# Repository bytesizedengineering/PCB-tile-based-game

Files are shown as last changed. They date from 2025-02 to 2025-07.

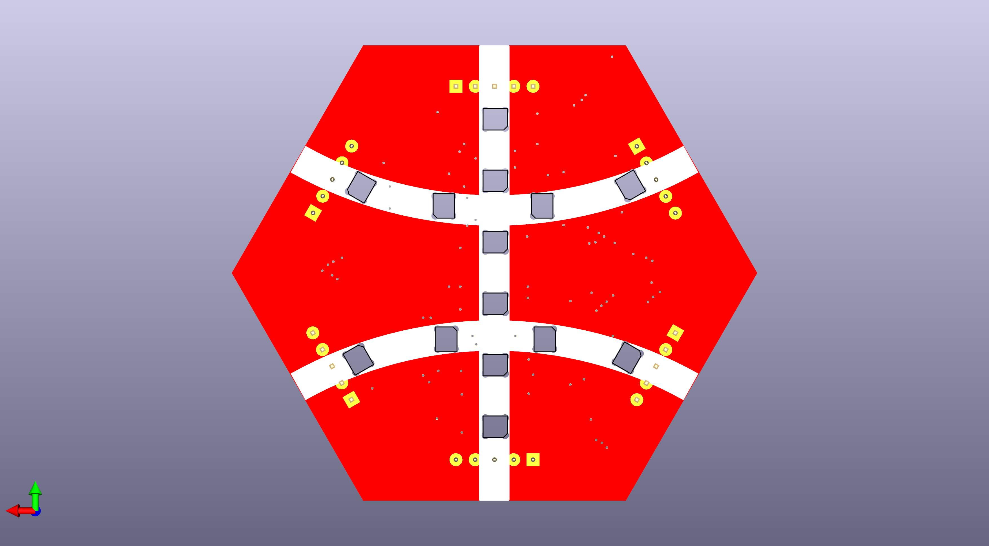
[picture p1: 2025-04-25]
Electrical Design/pcb_tile_game_tile_sos/pcb_tile_game_tile_sos.png

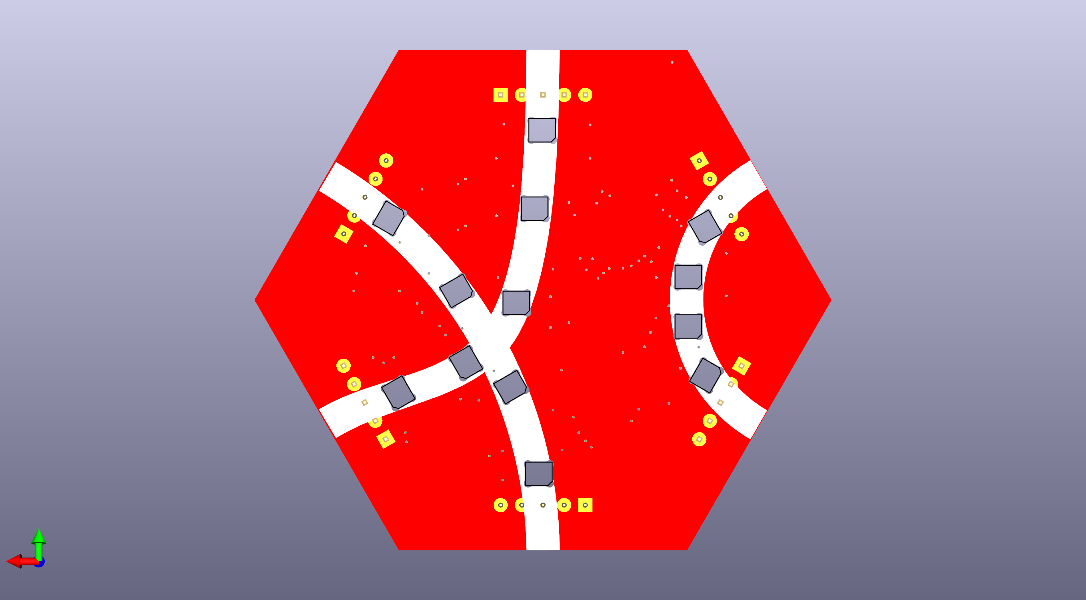
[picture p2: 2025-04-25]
Electrical Design/pcb_tile_game_tile_ssa/pcb_tile_game_tile_ssa.png

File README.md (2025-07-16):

# PCB Tile Based Board Game 

Project Image  
*Whoever completes the longest path wins! But beware of collisions!*  

## 🚀 Overview  
When Zach is not knee-deep in circuits and code, you can probably find him around a table covered in board games. For a long time now, a little project has been brewing in the back of his mind, designing a board game from the ground up, but not just any board game. Zach wants to create a tile-based game where the tiles electronically interact with each other the moment they snap together. It was featured on the Digkey [YouTube channel](https://www.youtube.com/@digikey) in [this video](https://youtu.be/TUmDfVxSnFg?si=vBeNglg9jUsEn66M).  

## 📂 Repository Structure  
```
📁 mechanical_design/   # 3D models (Fusion 360, STLs, STEP files)
📁 electrical_design/   # KiCad PCB and schematic files
📁 firmware/            # Arduino, ESP, or other firmware code
📁 docs/                # PDFs, images, and additional documentation
```

## 🔩 Mechanical Design  
You can access the latest Fusion 360 model here:  
[🔗 View 3D Model in Fusion 360](https://a360.co/4kI0F6f)

## 🏗️ Build Instructions  

### 🖨️ 3D Printing  
- **Recommended Material**: PLA/PETG  
- **Layer Height**: 0.2mm  
- **Supports**: No  

### 🔌 Electronics  
- **Microcontroller**: ATTiny3217  
- **Power Supply**: 5V  
- **PCB Fabrication**: Gerber files included in `electrical_design/` 

### 💾 Firmware Upload  
You can upload code to the ATtiny3217 using the [Adafruit UPDI Friend](https://learn.adafruit.com/adafruit-updi-friend). Here's a quick setup guide for the Arduino IDE:

🧰 What You Need
- Adafruit UPDI Friend
- Arduino IDE
- ATtiny3217 board
- USB-C cable
1. Install MegaTinyCore
2. Select the Board
3. Connect the UPDI Friend
4. Select the Serial Port
5. Upload Code

## 🛒 Bill of Materials (BOM)  
| Part | Description | Purchase Link |
| --- | --- | --- |
| Microcontroller | ATtiny3217 | [DigiKey](https://www.digikey.com/short/wtvwb0pv) |
| Connector | Magnetic Connector Pair | [DigiKey](https://www.digikey.com/short/tv5t94mz) |
| Capacitor | 0.1 µF Ceramic Capacitor | |
| LED | Addressable Reverse-Mount RGB LED | [DigiKey](https://www.digikey.com/short/zhvb3bff) |
| PCB | Custom-designed | |

## 🎥 Video & More Info  
📺 Watch the full build video: [YouTube Video](https://youtu.be/TUmDfVxSnFg?si=vBeNglg9jUsEn66M)  

## 📝 License  
This project is licensed under the **GNU General Public License v3.0**.  
You can read the full text in the [`LICENSE`](LICENSE) file or at [gnu.org](https://www.gnu.org/licenses/gpl-3.0.html).  

## ❤️ Support  
- Found this helpful? Consider supporting me on [Patreon](https://www.patreon.com/ByteSizedEngineering) or [YouTube Memberships](https://www.youtube.com/@ByteSizedEngineering/join).  
- Follow me on [YouTube](https://www.youtube.com/@ByteSizedEngineering), [Instagram](https://www.instagram.com/bytesizedengineering/), and [GitHub](https://github.com/bytesizedengineering).

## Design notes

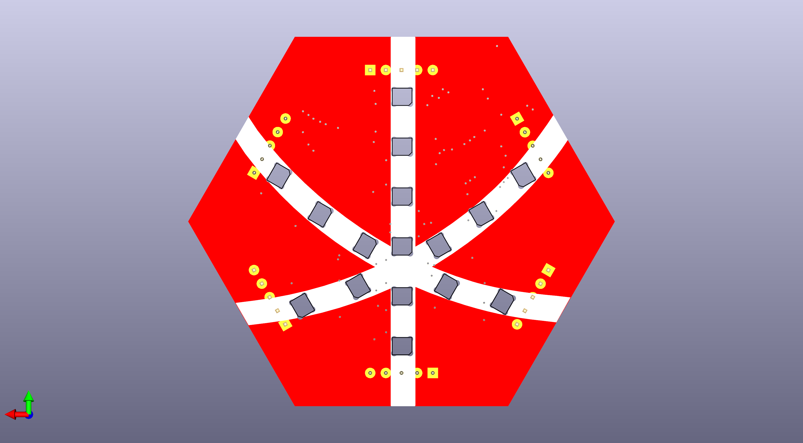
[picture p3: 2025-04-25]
Electrical Design/pcb_tile_game_tile_ooo/pcb_tile_game_tile_ooo.png

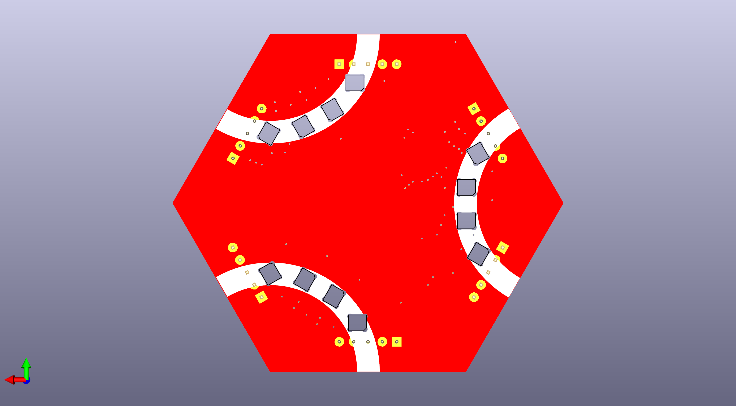
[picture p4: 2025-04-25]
Electrical Design/pcb_tile_game_tile_aaa/pcb_tile_game_tile_aaa.png

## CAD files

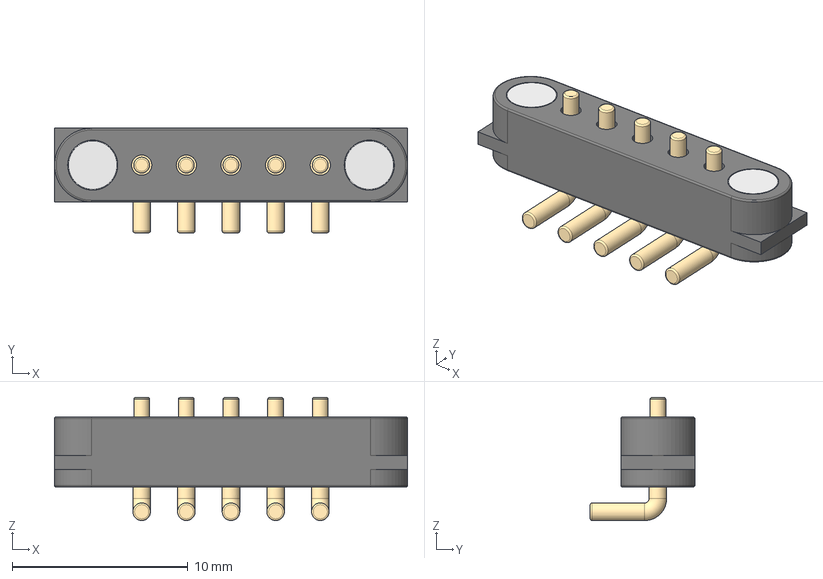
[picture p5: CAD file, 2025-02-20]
Electrical Design/pcb_tile_game_tile_aaa/5359 Mag Connector (5-pin, Right Angle, Pins).step
20.1 x 5.95 x 7.00 mm
Housing
Magnet
Pins
Pin Contacts

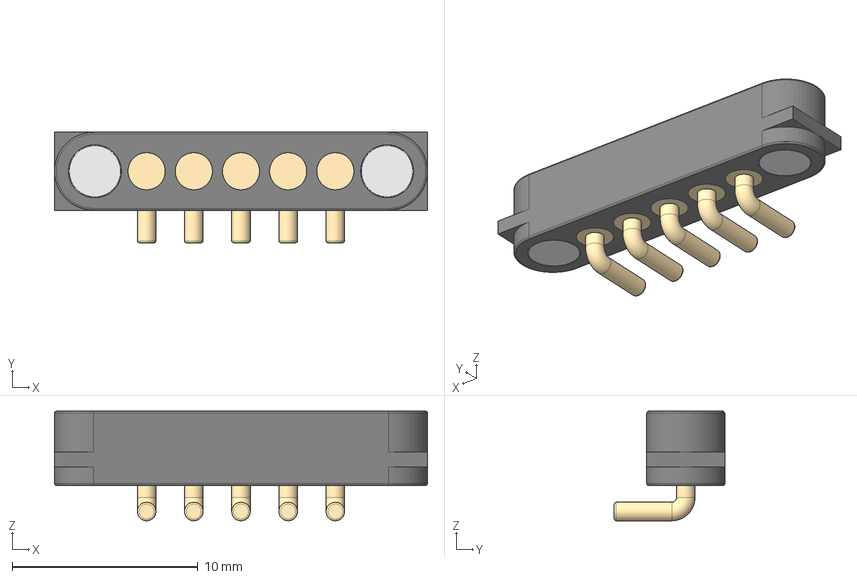
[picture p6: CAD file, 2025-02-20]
Electrical Design/pcb_tile_game_tile_aoa/5359 Mag Connector (5-pin, Right Angle, Pads).step
20.1 x 5.95 x 5.90 mm
Housing
Magnet
Pins

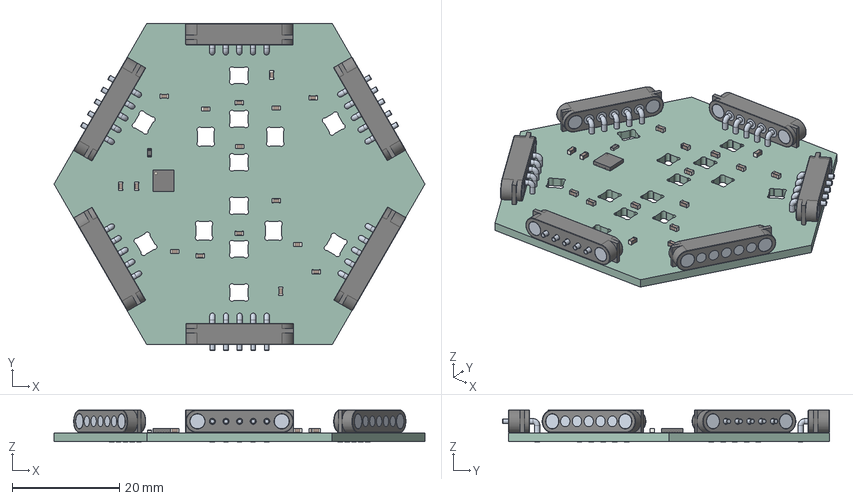
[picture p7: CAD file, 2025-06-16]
Electrical Design/pcb_tile_game_tile_sos/pcb_tile_game_tile_sos.step
69.3 x 61.1 x 5.95 mm
C_0603_1608Metric x 16
5359 Mag Connector (5-pin, Right Angle, Pins) v1 x 3
R_0603_1608Metric
5359 Mag Connector (5-pin, Right Angle, Pads) v1 x 3
QFN-24-1EP_4x4mm_Pitch0.5mm
pcb_tile_game_tile_sos_PCB

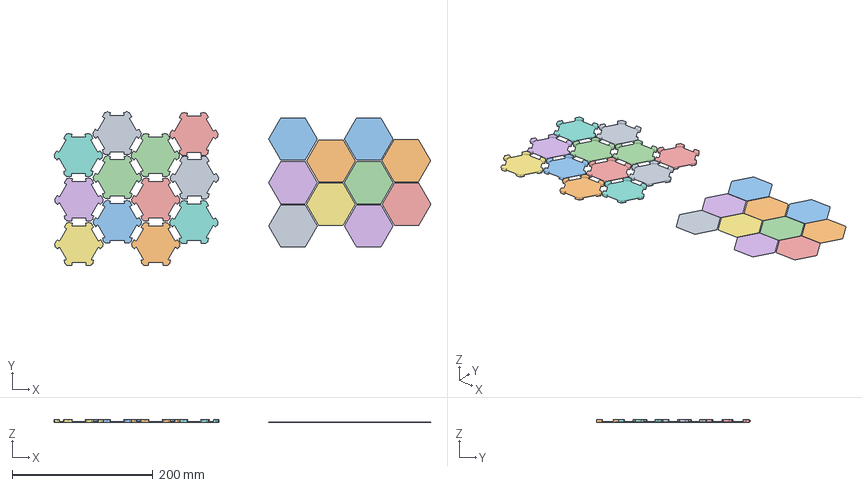
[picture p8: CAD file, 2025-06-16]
mechanical design/bambu project.3mf
535.3 x 218.0 x 4.25 mm
bottom 8 2
Assembly x 10
bottom
bottom 1
bottom 2 x 3
bottom 3
bottom 4
bottom 5
bottom 6
bottom 7
bottom 8

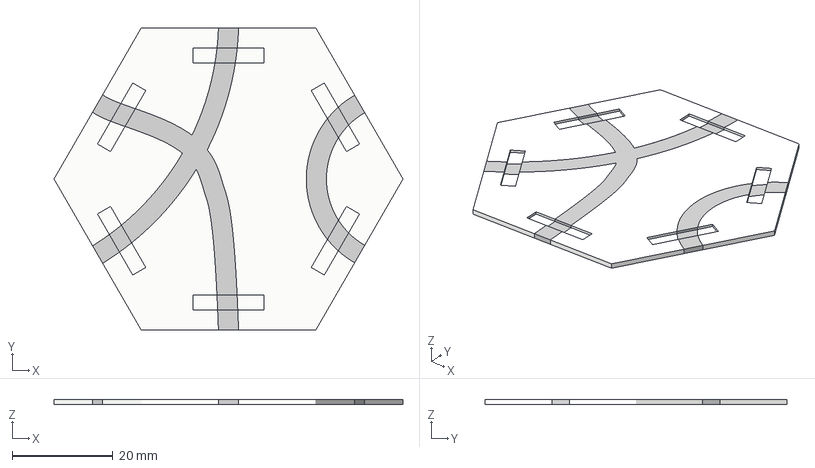
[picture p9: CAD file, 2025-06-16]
mechanical design/diffuser SSA.3mf
69.3 x 60.0 x 1.00 mm
diffuser (1)
diffuser (2)
diffuser (4)
diffuser (5)
diffuser

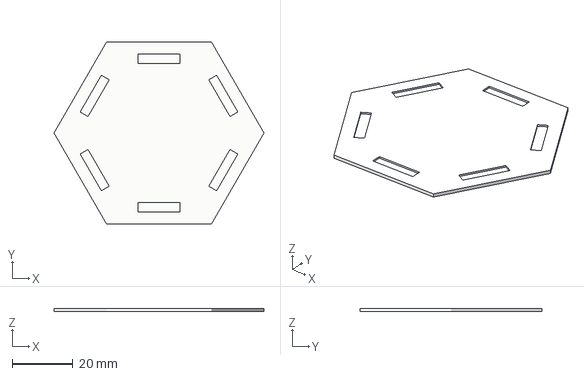
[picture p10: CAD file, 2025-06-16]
mechanical design/top.3mf
69.3 x 60.0 x 1.00 mm

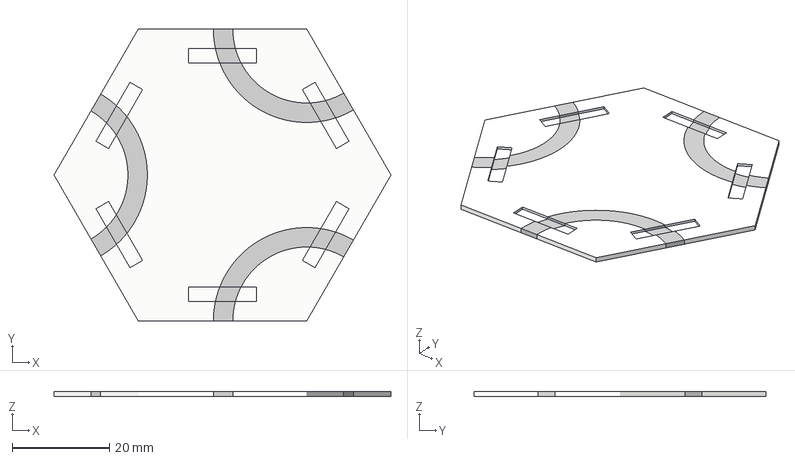
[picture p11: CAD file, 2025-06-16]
mechanical design/diffuser AAA.3mf
69.3 x 60.0 x 1.00 mm
diffuser (1)
diffuser (2)
diffuser (3)
diffuser

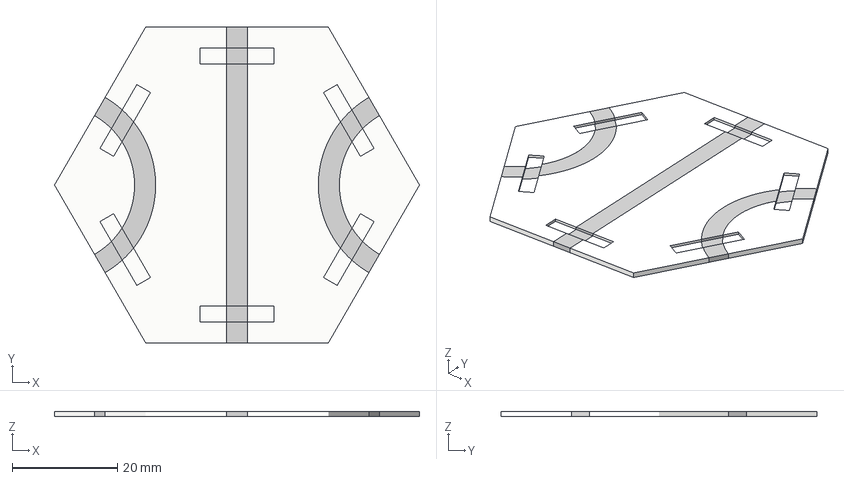
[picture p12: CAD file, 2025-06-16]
mechanical design/diffuser AOA.3mf
69.3 x 60.0 x 1.00 mm
diffuser (1)
diffuser (2)
diffuser (3)
diffuser

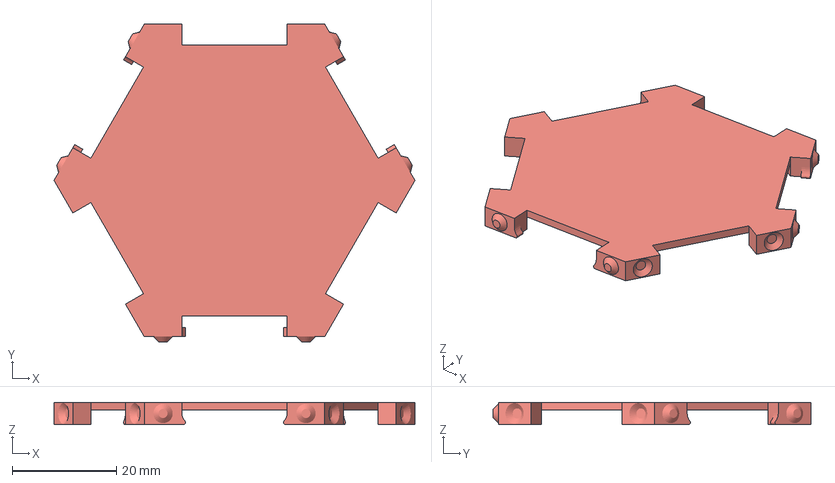
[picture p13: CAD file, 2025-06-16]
mechanical design/bottom.3mf
69.3 x 61.0 x 4.25 mm

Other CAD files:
mechanical design/diffuser SOS.3mf
mechanical design/diffuser OOO.3mf

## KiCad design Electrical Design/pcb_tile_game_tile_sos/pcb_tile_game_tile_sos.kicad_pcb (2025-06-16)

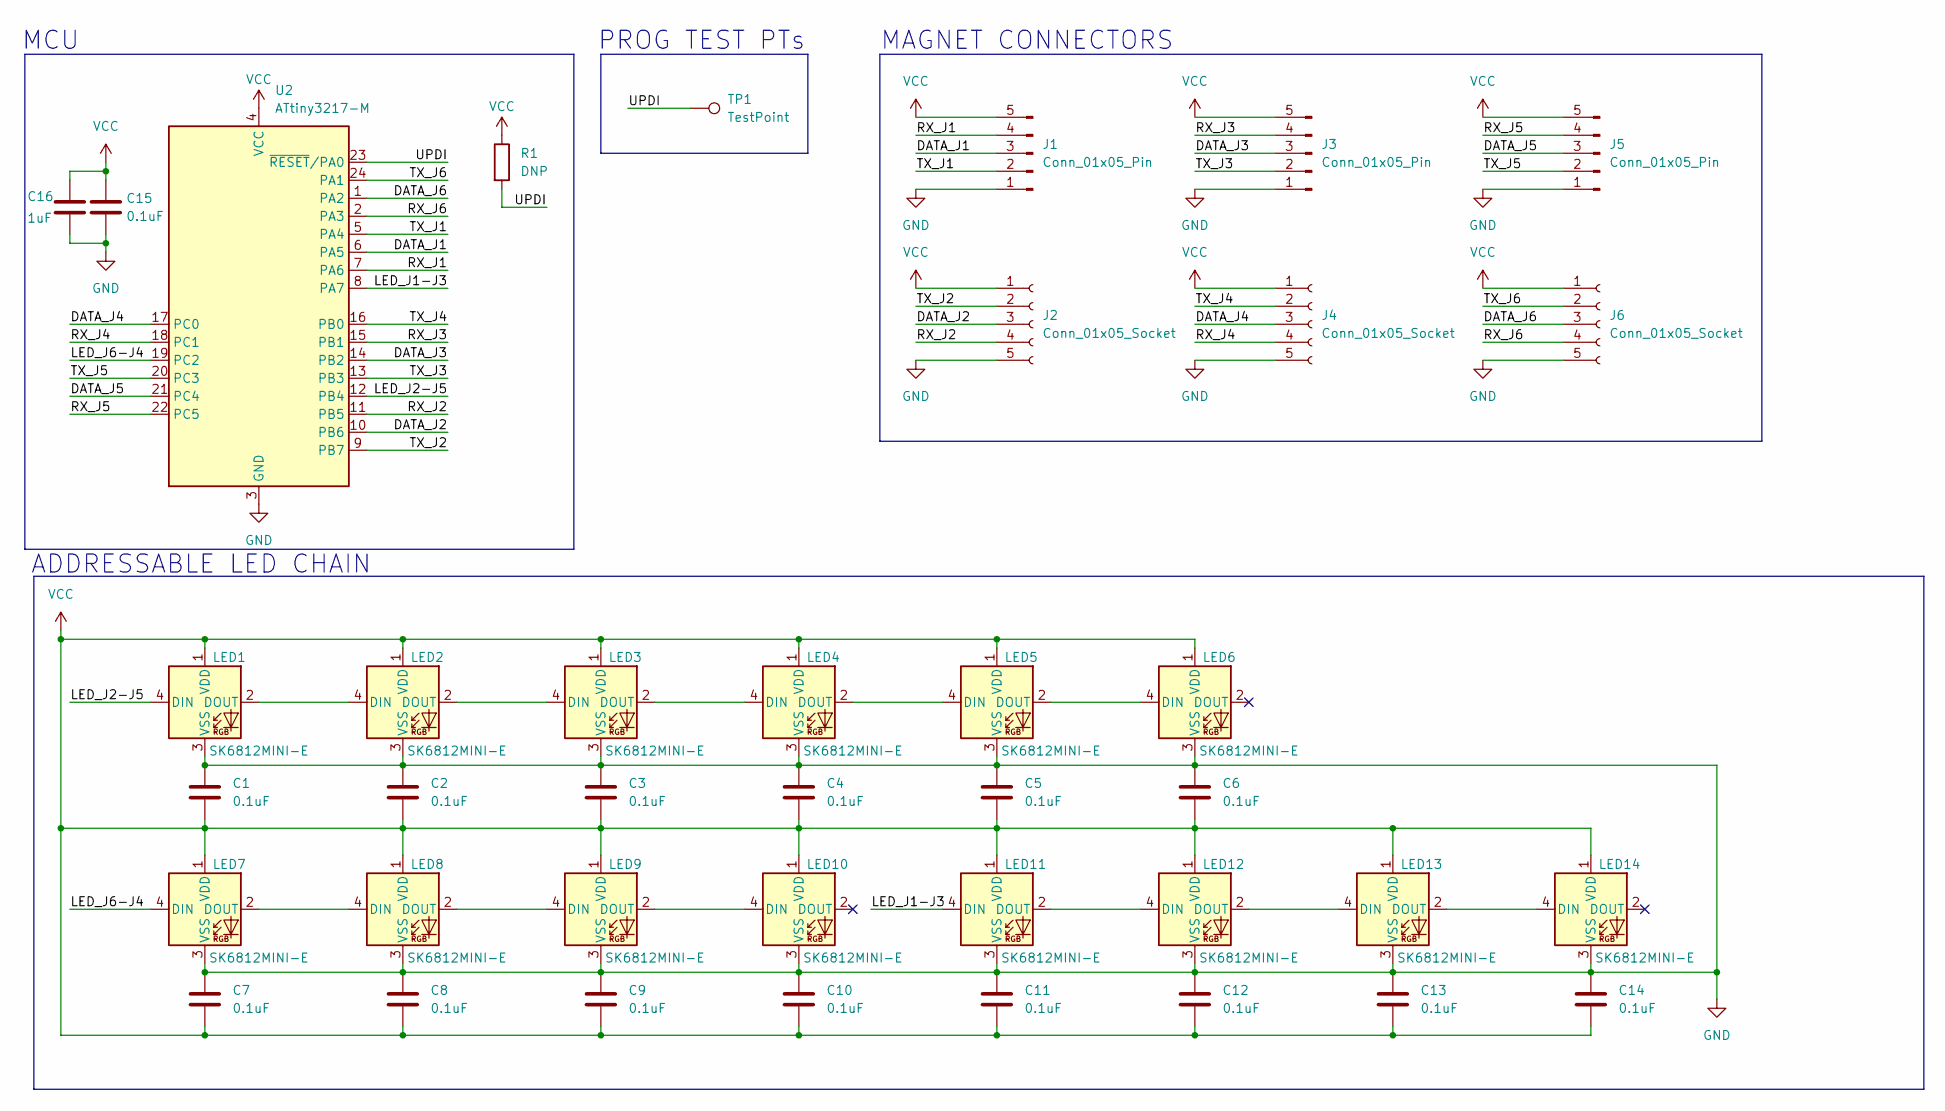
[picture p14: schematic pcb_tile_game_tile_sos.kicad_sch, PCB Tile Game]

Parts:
C1, C2, C3, C4, C5, C6, C7, C8, C9, C10, C11, C12, C13, C14, C15: 0.1uF; C_0603_1608Metric_Pad1.08x0.95mm_HandSolder
C16: 1uF; C_0603_1608Metric_Pad1.08x0.95mm_HandSolder
J1, J3, J5: Conn_01x05_Pin; PinHeader_1x05_P2.54mm_Vertical
J2, J4, J6: Conn_01x05_Socket; PinSocket_1x05_P2.54mm_Vertical
LED1, LED2, LED3, LED4, LED5, LED6, LED7, LED8, LED9, LED10, LED11, LED12, LED13, LED14: SK6812MINI-E; DigiKey Part Number 1528-4960-ND
R1: DNP; R_0603_1608Metric_Pad0.98x0.95mm_HandSolder
TP1: TestPoint; TestPoint_Pad_2.0x2.0mm
U2: ATtiny3217-M; QFN-24-1EP_4x4mm_P0.5mm_EP2.6x2.6mm

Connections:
/DATA_J1: J1.3, U2.6 (PA5)
/DATA_J2: J2.3, U2.10 (PB6)
/DATA_J3: J3.3, U2.14 (PB2)
/DATA_J4: J4.3, U2.17 (PC0)
/DATA_J5: J5.3, U2.21 (PC4)
/DATA_J6: J6.3, U2.1 (PA2)
/LED_J1-J6: LED11.4 (DIN), U2.8 (PA7)
/LED_J2-J5: LED1.4 (DIN), U2.12 (PB4)
/LED_J3-J4: LED7.4 (DIN), U2.19 (PC2)
/RX_J1: J1.4, U2.7 (PA6)
/RX_J2: J2.4, U2.11 (PB5)
/RX_J3: J3.4, U2.15 (PB1)
/RX_J4: J4.4, U2.18 (PC1)
/RX_J5: J5.4, U2.22 (PC5)
/RX_J6: J6.4, U2.2 (PA3)
/TX_J1: J1.2, U2.5 (PA4)
/TX_J2: J2.2, U2.9 (PB7)
/TX_J3: J3.2, U2.13 (PB3)
/TX_J4: J4.2, U2.16 (PB0)
/TX_J5: J5.2, U2.20 (PC3)
/TX_J6: J6.2, U2.24 (PA1)
/UPDI: R1.2, TP1.1, U2.23 (~RESET/PA0)
GND: C1.1, C2.1, C3.1, C4.1, C5.1, C6.1, C7.1, C8.1, C9.1, C10.1, C11.1, C12.1, C13.1, C14.1, C15.2, C16.2, J1.1, J2.5, J3.1, J4.5, J5.1, J6.5, LED1.3 (VSS), LED2.3 (VSS), LED3.3 (VSS), LED4.3 (VSS), LED5.3 (VSS), LED6.3 (VSS), LED7.3 (VSS), LED8.3 (VSS), LED9.3 (VSS), LED10.3 (VSS), LED11.3 (VSS), LED12.3 (VSS), LED13.3 (VSS), LED14.3 (VSS), U2.3 (GND), U2.25 (GND)
unnamed: LED1.2 (DOUT), LED2.4 (DIN)
unnamed: LED2.2 (DOUT), LED3.4 (DIN)
unnamed: LED3.2 (DOUT), LED4.4 (DIN)
unnamed: LED4.2 (DOUT), LED5.4 (DIN)
unnamed: LED5.2 (DOUT), LED6.4 (DIN)
unnamed: LED7.2 (DOUT), LED8.4 (DIN)
unnamed: LED8.2 (DOUT), LED9.4 (DIN)
unnamed: LED9.2 (DOUT), LED10.4 (DIN)
unnamed: LED11.2 (DOUT), LED12.4 (DIN)
unnamed: LED12.2 (DOUT), LED13.4 (DIN)
unnamed: LED13.2 (DOUT), LED14.4 (DIN)
VCC: C1.2, C2.2, C3.2, C4.2, C5.2, C6.2, C7.2, C8.2, C9.2, C10.2, C11.2, C12.2, C13.2, C14.2, C15.1, C16.1, J1.5, J2.1, J3.5, J4.1, J5.5, J6.1, LED1.1 (VDD), LED2.1 (VDD), LED3.1 (VDD), LED4.1 (VDD), LED5.1 (VDD), LED6.1 (VDD), LED7.1 (VDD), LED8.1 (VDD), LED9.1 (VDD), LED10.1 (VDD), LED11.1 (VDD), LED12.1 (VDD), LED13.1 (VDD), LED14.1 (VDD), R1.1, U2.4 (VCC)

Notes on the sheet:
PROG TEST PTs
MCU
ADDRESSABLE LED CHAIN
MAGNET CONNECTORS

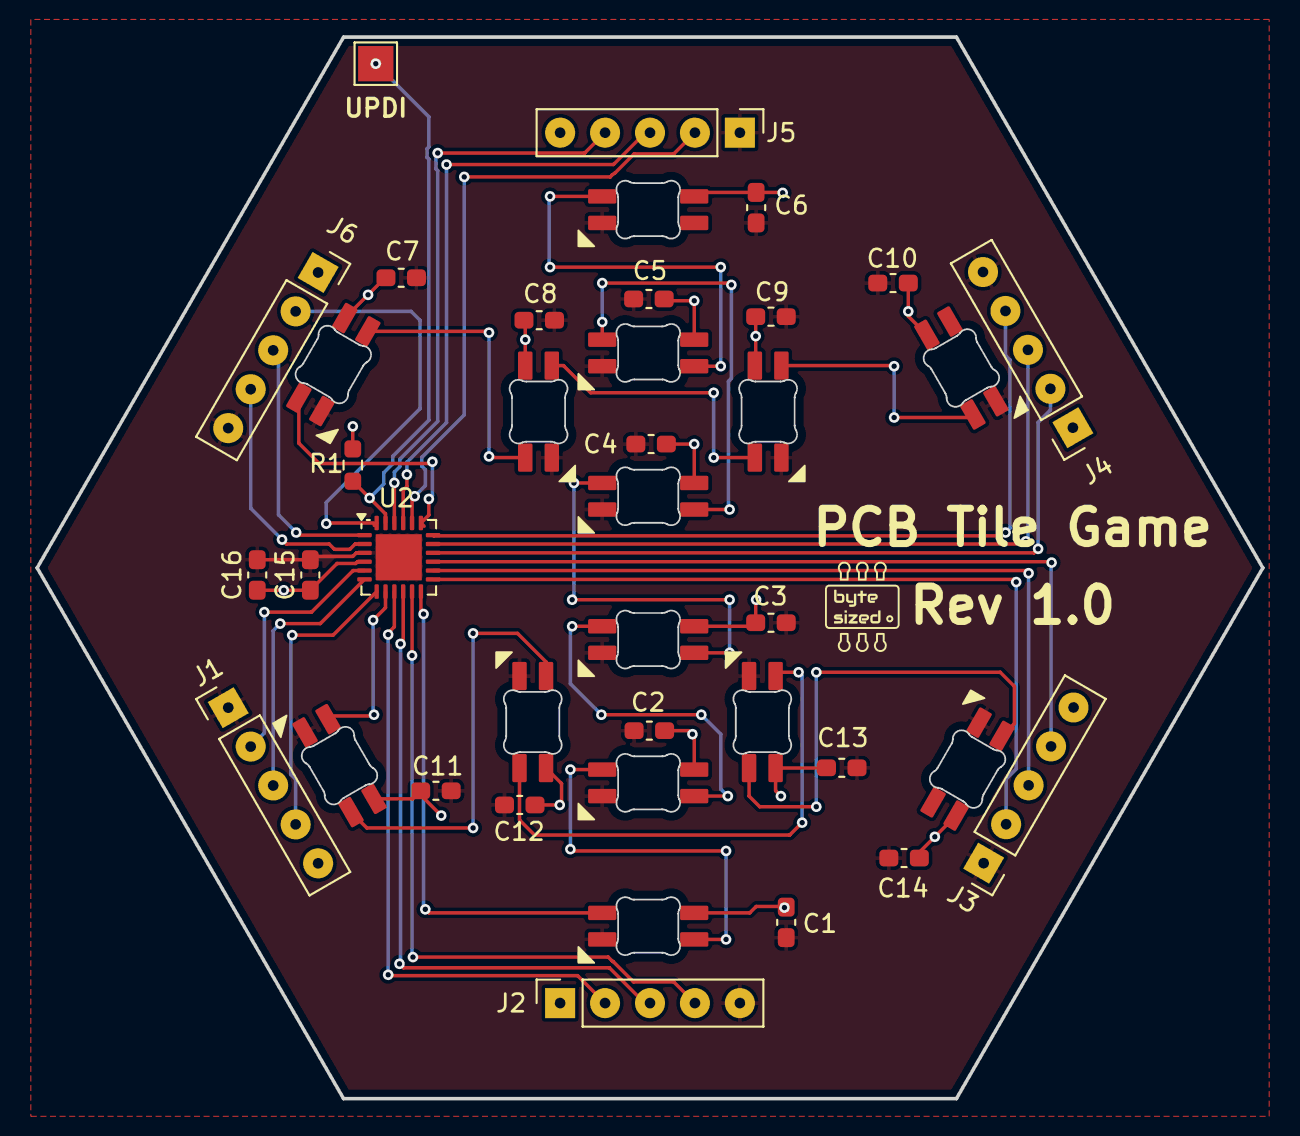
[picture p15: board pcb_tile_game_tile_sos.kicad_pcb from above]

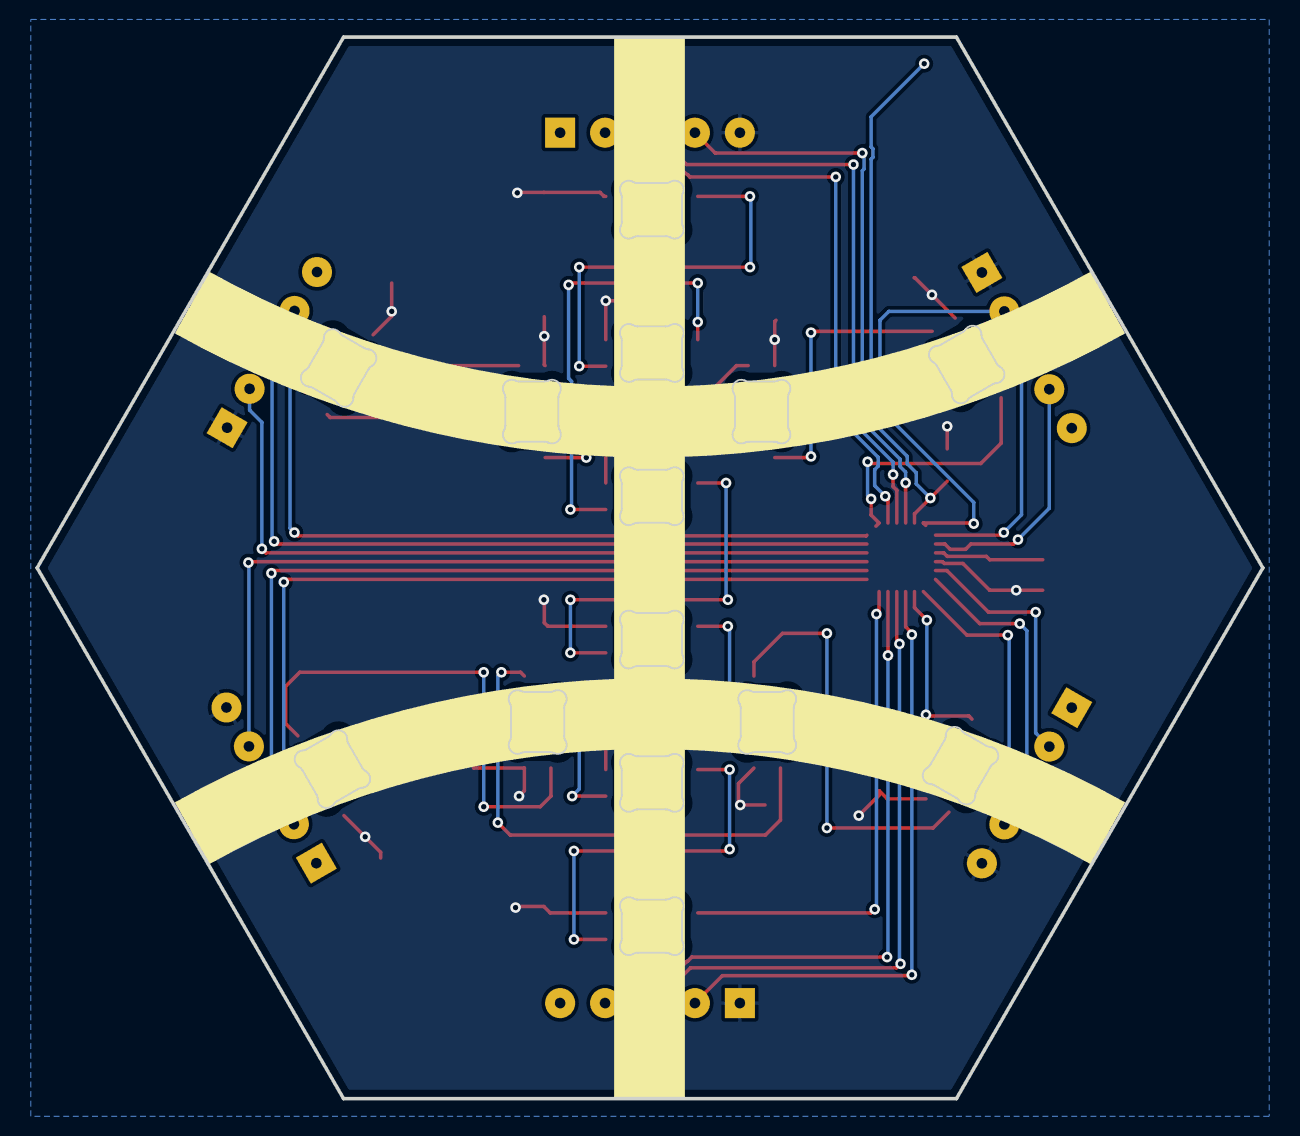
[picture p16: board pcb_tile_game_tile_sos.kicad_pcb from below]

Board: 2 copper layers, 69.3 x 60.0 mm, 39 parts (14 on the bottom side), 35 nets.

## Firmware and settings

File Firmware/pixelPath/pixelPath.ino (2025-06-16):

#include <tinyNeoPixel.h>

// Uncomment only one of these to select the tile type
//#define TILE_TYPE_AAA
//#define TILE_TYPE_AOA
//#define TILE_TYPE_OOO
//#define TILE_TYPE_SOS
#define TILE_TYPE_SSA

// Uncomment the following line to create a starting tile
// Leave commented for all other standard tiles
//#define TILE_TYPE_SARTING

// Structures
struct Connector {
  const char* name; // This stores the PCB connector name J1, J3, etc. 
  uint8_t pin_red; // This stores which MCU pin is connected to pin 2 on the connector
  uint8_t pin_green; // This stores which MCU pin is connected to pin 3 on the connector
  uint8_t pin_blue; // This stores which MCU pin is connected to pin 4 on the connector
};
struct Path {
  int sideA; // This stores which connector is considered side A (J1, J5, etc)
  int sideB; // This stores which connector is considered side B (J1, J5, etc)
  int ledPin; // This stores which MCU pin controls the neopixels
  int numLEDs; // This stores how many neopixels total are in the path
  tinyNeoPixel pixelPath; // neopixel instance 

  // Runtime animation state
  int animStep = 0; // This stores how many pixels are currently lit up during an animation
  bool active = false; // This stores whether or not the path is currently lit up
  bool direction = true; // This stores which side has color data present, also which direction the animation needs to go. True = sideA → sideB
  uint32_t color = 0; // 32 bit color that will be shown on the LEDs when animated
};
struct Tile {
  Path path1;
  Path path2;
  Path path3;

  void begin() {
    path1.pixelPath = tinyNeoPixel(path1.numLEDs, path1.ledPin, NEO_GRB + NEO_KHZ800);
    path2.pixelPath = tinyNeoPixel(path2.numLEDs, path2.ledPin, NEO_GRB + NEO_KHZ800);
    path3.pixelPath = tinyNeoPixel(path3.numLEDs, path3.ledPin, NEO_GRB + NEO_KHZ800);

    path1.pixelPath.begin(); path1.pixelPath.clear(); path1.pixelPath.show();
    path2.pixelPath.begin(); path2.pixelPath.clear(); path2.pixelPath.show();
    path3.pixelPath.begin(); path3.pixelPath.clear(); path3.pixelPath.show();
  }
};

// Global variables
Connector connectors[] = {
  {"", 0, 0, 0},  // Dummy to make indexing start at 1
  {"J1", PIN_PA4, PIN_PA5, PIN_PA6}, // This stores which MCU pin is connected to pins 2,3, and 4 on the connector
  {"J2", PIN_PB7, PIN_PB6, PIN_PB5},
  {"J3", PIN_PB3, PIN_PB2, PIN_PB1},
  {"J4", PIN_PB0, PIN_PC0, PIN_PC1},
  {"J5", PIN_PC3, PIN_PC4, PIN_PC5},
  {"J6", PIN_PA1, PIN_PA2, PIN_PA3},
};

Tile tile; // This is the top level variable to access everything that goes on within the tile
unsigned long lastPathUpdate = 0; // This stores how long it's been since the last time each path was updated

void setup() {  
  for (int i = 1; i <= 6; i++) {
    pinMode(connectors[i].pin_red, INPUT_PULLUP);
    pinMode(connectors[i].pin_green, INPUT_PULLUP);
    pinMode(connectors[i].pin_blue, INPUT_PULLUP);
  }
  assignTileType();

  tile.begin();

  #if defined (TILE_TYPE_SARTING)
    tile.path1.color = 0x007F0000; // Red
    tile.path2.color = 0x00007F00; // Green
    tile.path3.color = 0x0000007F; // Blue

    activateStartingPath(tile.path1);
    activateStartingPath(tile.path2);
    activateStartingPath(tile.path3);
    while(true);
  #endif
}

void loop() {  
  if(millis() - lastPathUpdate > 200){
    lastPathUpdate = millis();
    updatePath(tile.path1, connectors);
    updatePath(tile.path2, connectors);
    updatePath(tile.path3, connectors);    
  }
}

void assignTileType(){
  #if defined(TILE_TYPE_AAA)
    tile = {
      {.sideA = 1, .sideB = 6, .ledPin = PIN_PA7, .numLEDs = 4},  // Adjacent J1 ↔ J6
      {.sideA = 2, .sideB = 3, .ledPin = PIN_PB4, .numLEDs = 4},  // Adjacent J2 ↔ J3
      {.sideA = 4, .sideB = 5, .ledPin = PIN_PC2, .numLEDs = 4}   // Adjacent J4 ↔ J5
    };
  #elif defined(TILE_TYPE_AOA)
    tile = {
      {.sideA = 1, .sideB = 6, .ledPin = PIN_PA7, .numLEDs = 4},  // Adjacent J1 ↔ J6
      {.sideA = 2, .sideB = 5, .ledPin = PIN_PB4, .numLEDs = 6},  // Opposite J2 ↔ J5
      {.sideA = 3, .sideB = 4, .ledPin = PIN_PC2, .numLEDs = 4}   // Adjacent J3 ↔ J4
    };
  #elif defined(TILE_TYPE_OOO)
    tile = {
      {.sideA = 4, .sideB = 1, .ledPin = PIN_PB4, .numLEDs = 5},  // Opposite J1 ↔ J4
      {.sideA = 5, .sideB = 2, .ledPin = PIN_PC2, .numLEDs = 6},  // Opposite J2 ↔ J5
      {.sideA = 6, .sideB = 3, .ledPin = PIN_PA7, .numLEDs = 5}   // Opposite J3 ↔ J6
    };
  #elif defined(TILE_TYPE_SOS)
    tile = {
      {.sideA = 1, .sideB = 3, .ledPin = PIN_PA7, .numLEDs = 4},  // Skip     J1 ↔ J3 
      {.sideA = 2, .sideB = 5, .ledPin = PIN_PB4, .numLEDs = 6},  // Opposite J2 ↔ J5
      {.sideA = 6, .sideB = 4, .ledPin = PIN_PC2, .numLEDs = 4}   // Skip     J6 ↔ J4 
    };
  #elif defined(TILE_TYPE_SSA)
    tile = {
      {.sideA = 2, .sideB = 4, .ledPin = PIN_PB4, .numLEDs = 4},  // Skip     J2 ↔ J4  
      {.sideA = 3, .sideB = 5, .ledPin = PIN_PC2, .numLEDs = 5},  // Skip     J3 ↔ J5
      {.sideA = 1, .sideB = 6, .ledPin = PIN_PA7, .numLEDs = 4}   // Adjacent J1 ↔ J6
    };
  #else
    #error "No TILE_TYPE defined!"
  #endif
}

void animatePath(tinyNeoPixel &path, int animStep, int numLEDs, bool sideAtoSideB, uint32_t color){  
  path.clear();
  //path.show();
  if(sideAtoSideB){
    for (int i = 0; i < animStep && i < numLEDs; i++) {
      path.setPixelColor(i, color);
    }
  }
  else{
    for (int i = numLEDs - 1; i >= numLEDs - animStep && i >= 0; i--) {
      path.setPixelColor(i, color);
    }
  }
  path.show();
}

uint32_t readConnectorColor(const Connector& conn) {


  // Read each pin (they're pulled up, so LOW means active)
  bool red   = !digitalRead(conn.pin_red);
  bool green = !digitalRead(conn.pin_green);
  bool blue  = !digitalRead(conn.pin_blue);

  // Pack BGR bits (Red is LSB)
  uint8_t colorBits = (blue << 2) | (green << 1) | red;

  // Convert to 32-bit NeoPixel color (GRB ordering)
  switch (colorBits) {
    case 0b000: return 0x00000000; // Off
    case 0b001: return 0x007F0000; // Red
    case 0b010: return 0x00007F00; // Green
    case 0b011: return 0x007F7F00; // Yellow
    case 0b100: return 0x0000007F; // Blue
    case 0b101: return 0x007F007F; // Magenta
    case 0b110: return 0x00007F7F; // Cyan
    case 0b111: return 0x007F7F7F; // White
    default:    return 0x00000000; // Fallback (Off)
  }
}

void updatePath(Path& path, const Connector* connectors) {
  uint32_t colorA = 0;
  uint32_t colorB = 0;

  // Set colorA and colorB, but be careful not to try and read pins that are already set to OUTPUT!!!!
  if (path.active) { // One of the sides has already been set as an OUTPUT so it shouldn't be evaluated for color data
    if (path.direction) { // Side A has color
      colorA = readConnectorColor(connectors[path.sideA]); //Only read the side that is an input, not the side that's an output      
    }
    else { // Side B has color
      colorB = readConnectorColor(connectors[path.sideB]); //Only read the side that is an input, not the side that's an output      
    }
  }
  else { // No active colors detected. It's safe to read both sides
    colorA = readConnectorColor(connectors[path.sideA]); //Only read the side that is an input, not the side that's an output
    colorB = readConnectorColor(connectors[path.sideB]); //Only read the side that is an input, not the side that's an output
  }

  if(colorA && !colorB) {
    path.direction = true; 
    path.color = colorA;    
        
    setConnectorInput(connectors[path.sideA]); // Make sure sideA stays input
    path.active = true;
  }  
  else if(colorB && !colorA) {
    path.direction = false;
    path.color = colorB;        
    setConnectorInput(connectors[path.sideB]);
    path.active = true;
  }
  else if (colorA && colorB) {
    static bool toggle = false;
    toggle = !toggle;
    if (colorA == colorB) { // single player closed their loop      
      if (toggle) path.pixelPath.fill(colorA);
      else path.pixelPath.clear();
    }
    else { // two players' paths have collided
      if (toggle) path.pixelPath.fill(colorA);
      else path.pixelPath.fill(colorB);      
    }
    path.pixelPath.show();
  }
  else { // No color data is present on either side of path
    // Clear path and reset
    path.pixelPath.clear(); path.pixelPath.show();
    //path.color = 0;    
    path.animStep = 0;
    // Set both sides to input
    setConnectorInput(connectors[path.sideA]);
    setConnectorInput(connectors[path.sideB]);
    path.active = false;
    return; // no need to evaluate the rest of this function because this path is not active
  }

  if (path.active && path.animStep <= path.numLEDs) { //If the path is active, animate animStep number of LEDs in the direction and color established above
    animatePath(path.pixelPath, path.animStep, path.numLEDs, path.direction, path.color);
    path.animStep++; // Increment the number of LEDs to animate for the next go around
    if (path.animStep > path.numLEDs) {
      // Animation finished, now mirror the color
      if (path.direction) setConnectorOutput(connectors[path.sideB], path.color); // Mirror to sideB
      else setConnectorOutput(connectors[path.sideA], path.color); // Mirror to sideA
      //path.active = false;      
    }
  }
}

void setConnectorOutput(const Connector& conn, uint32_t color) {
  bool red = (color & 0x00FF0000) != 0;
  bool green = (color & 0x0000FF00) != 0;
  bool blue = (color & 0x000000FF) != 0;

  pinMode(conn.pin_red, OUTPUT);
  pinMode(conn.pin_green, OUTPUT);
  pinMode(conn.pin_blue, OUTPUT);

  digitalWrite(conn.pin_red, blue ? LOW : HIGH); // needed to swap blue/red because the PCB was routed to mate tx/rx pairs
  digitalWrite(conn.pin_green, green ? LOW : HIGH);
  digitalWrite(conn.pin_blue, red ? LOW : HIGH); // needed to swap blue/red because the PCB was routed to mate tx/rx pairs
}

void setConnectorInput(const Connector& conn) {
  pinMode(conn.pin_red, INPUT_PULLUP);
  pinMode(conn.pin_green, INPUT_PULLUP);
  pinMode(conn.pin_blue, INPUT_PULLUP);
}

void activateStartingPath(Path& path) {
  path.pixelPath.fill(path.color);
  path.pixelPath.show();

  setConnectorOutput(connectors[path.sideA], path.color);
  setConnectorOutput(connectors[path.sideB], path.color);
}

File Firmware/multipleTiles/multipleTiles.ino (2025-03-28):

#define RX_J1 PIN_PA6
#define TX_J1 PIN_PA4
#define DATA_J1 PIN_PA5

#define RX_J2 PIN_PB5
#define TX_J2 PIN_PB7
#define DATA_J2 PIN_PB6

#define RX_J3 PIN_PB1
#define TX_J3 PIN_PB3
#define DATA_J3 PIN_PB2

#define RX_J4 PIN_PC1
#define TX_J4 PIN_PB0
#define DATA_J4 PIN_PC0

#define RX_J5 PIN_PC5
#define TX_J5 PIN_PC3
#define DATA_J5 PIN_PC4

#define RX_J6 PIN_PA3
#define TX_J6 PIN_PA1
#define DATA_J6 PIN_PA2

#define LED_J2_J5 PIN_PB4
#define LED_J3_J4 PIN_PC2
#define LED_J1_J6 PIN_PA7

#include <SoftwareSerial.h>
#include <tinyNeoPixel.h>


// define SoftwareSerial objects
SoftwareSerial J1Serial (RX_J1, TX_J1);
SoftwareSerial J2Serial (RX_J2, TX_J2);
SoftwareSerial J3Serial (RX_J3, TX_J3);
SoftwareSerial J4Serial (RX_J4, TX_J4);
SoftwareSerial J5Serial (RX_J5, TX_J5);
SoftwareSerial J6Serial (RX_J6, TX_J6);

// define tinyNeoPixel objects
tinyNeoPixel pixels_J2_J5 = tinyNeoPixel(6, LED_J2_J5, NEO_GRB + NEO_KHZ800);
tinyNeoPixel pixels_J3_J4 = tinyNeoPixel(4, LED_J3_J4, NEO_GRB + NEO_KHZ800);
tinyNeoPixel pixels_J1_J6 = tinyNeoPixel(4, LED_J1_J6, NEO_GRB + NEO_KHZ800);

void setup() {
  // begin all serial instances
  Serial.begin(115200);
  J1Serial.begin(9600);
  J2Serial.begin(9600);
  J3Serial.begin(9600);
  J4Serial.begin(9600);
  J5Serial.begin(9600);
  J6Serial.begin(9600);

  // Initialize all tinyNeoPixel strands.
  pixels_J2_J5.begin(); pixels_J2_J5.clear();
  pixels_J3_J4.begin(); pixels_J3_J4.clear();
  pixels_J1_J6.begin(); pixels_J1_J6.clear();

}

void loop() {
  if (J1Serial.available() >= 3) {    
    byte red = J1Serial.read();
    byte green = J1Serial.read();
    byte blue = J1Serial.read();
    Serial.print("J1Serial received: "); Serial.print(red); Serial.print(green); Serial.println(blue);
    colorWipe("J1", red, green, blue);
  }
  Serial.println("looping");
}

void colorWipe(String side, byte redValue, byte greenValue, byte blueValue){
  if(side == "J1"){
    for (int i = 0; i < 4; i++) {
    pixels_J1_J6.setPixelColor(i, pixels_J1_J6.Color(redValue, greenValue, blueValue)); 
    pixels_J1_J6.show(); // This sends the updated pixel color to the hardware.
    delay(500); // Delay for a period of time (in milliseconds).
  }
  }
}

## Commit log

2025-02-20 updated 3D models and silkscreen
    Added magnetic connector models, LED models, changed path thickness, added title, revision, and logo to silkscreen.
    [5359 Mag Connector (5-pin, Right Angle, Pads).step, 5359 Mag Connector (5-pin, Right Angle, Pins).step, WS2812-2020.STEP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]
2025-02-21 Updated pcb layout
    rerouted all traces, adjusted position of LEDs and silkscreen.
    [pcb_tile_game-B_Cu.gbr, pcb_tile_game-B_Fab.gbr, pcb_tile_game-B_Mask.gbr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]
2025-03-28 Firmware, and capacitor
    Added firmware folder, and added additional capacitor in parallel to C15 in schematic. Footprint still needs to be added
    [pcb_tile_game-B_Cu.gbr, pcb_tile_game-B_Fab.gbr, pcb_tile_game-B_Mask.gbr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]
2025-04-07 Create 5 variant tiles. Decrease mag connector hole size. Change path silkscreen to 4mm wide.
    [5359 Mag Connector (5-pin, Right Angle, Pads).step, 5359 Mag Connector (5-pin, Right Angle, Pins).step, WS2812-2020.STEP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]
2025-04-07 Change PCB version to 1.0
    [pcb_tile_game_tile_aaa.kicad_pcb, pcb_tile_game_tile_aoa.kicad_pcb, pcb_tile_game_tile_ooo.kicad_pcb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]
2025-04-15 created gerbers
    [WS2812-2020.STEP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]
2025-04-25 firmware added
    I wrote a unified code base for all pattern types. The unifiedTest code tests all LEDs and all connector pins as inputs
2025-06-16 updated PCB design, mechanical design
    [USB C power adapter.kicad_pcb, USB C power adapter.kicad_sch, bambu project.3mf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]
